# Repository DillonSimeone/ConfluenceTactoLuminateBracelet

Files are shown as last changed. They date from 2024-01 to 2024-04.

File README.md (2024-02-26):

<h1 align="center"><a href="https://bejewelled-kelpie-6a1941.netlify.app/">Gestolumina</a></h1>
<h4 align="center">Gesture Interpreted Light, Sound and Haptics. Towards a Framework for Universal Music Design</h4>

<p align="center">
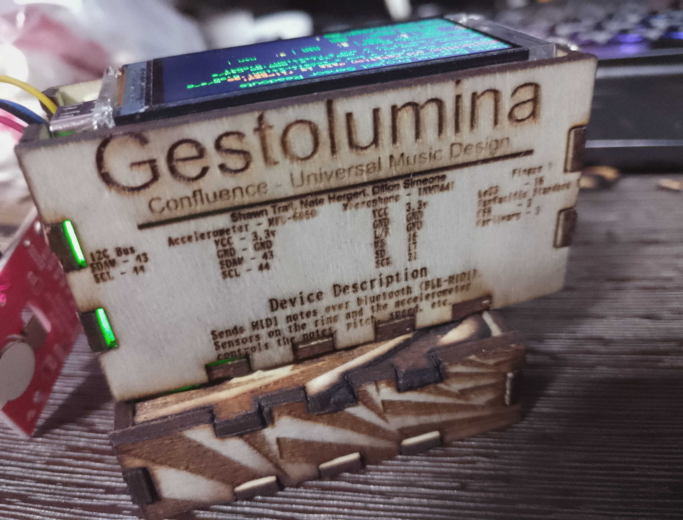
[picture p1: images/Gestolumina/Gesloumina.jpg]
    
</p>
<h1 align="center">Team Members</h1>
<table align="center">
    <thead>
        <th>Shawn Trail, PhD</th>
        <th>Nate Hergert</th>
        <th>Myles De Bastion</th>
    </thead>
    <tbody>
        <tr>   
            <td>CymaSpace</td>
            <td>CymaSpace</td>
            <td>CymaSpace</td>
        </tr>
        <tr>
            <td>www.cymaspace.org</td>
            <td>www.cymaspace.org</td>
            <td>www.cymaspace.org</td>
        </tr>
        <tr>
            <td>Portland, Oregon</td>
            <td>Portland, Oregon</td>
            <td>Portland, Oregon</td>
        </tr>
        <tr>
            <td>shawntrail@gmail.com</td>
            <td>nate@cymaspace.org</td>
            <td>myles@cymaspace.org</td>
        </tr>
    </tbody>
    
</table>
<table align="center">
    <thead>
        <th>Dillon Simeone</th>
        <th>Doga Cavdir, PhD</th>
        <th>Duncan MacConnell, PhD</th>
    </thead>
    <tbody>
    <tr>
        <td>CymaSpace</td>
        <td>Medialogy</td>
        <td>Avid</td>
    </tr>
    <tr>
        <td>www.cymaspace.org</td>
        <td>Aalborg University</td>
        <td><a href="https://www.linkedin.com/in/duncan-macconnell-a4067511a/overlay/contact-info/">linkedIn</a></td>
    </tr>
    <tr>
        <td>Portland, Oregon</td>
        <td>Copnenhagen, Denmark</td>
        <td>Montreal, Quebec, Canada</td>
    </tr>
    <tr>
        <td>dillonsimeone@gmail.com</td>
        <td>Idoga.cadvir@gmail.com</td>
        <td>duncanmacconnell@gmail.com</td>
    </tr>
    </tbody>
</table>

# Intro
<p>
    Two different styles of bracelets are being built as custom musical instruments, one with pixelblaze and another with ESP32. The purpose of those bracelets are to control nearly haptics and LED systems via sensors detecting the wearer's gestures and movements. 
</p>
<h3><a href="https://github.com/DillonSimeone/Gestolumina/tree/main/Arduino%20Code">ESP32 Bracelet (GestoLumina)</a></h3>
<p>A low cost but extremely powerful approach, very beginner-friendly due to being programmed in arduino. Require more elbow grease to get up and running similar to the pixelblaze. However, the bluetooth in nearly all ESP32s makes them very easy to program as bluetooth musical instruments!</p>

<h3><a href="https://github.com/DillonSimeone/Gestolumina/tree/main/Pixelblaze%20Code">Pixelblaze Bracelet</a></h3>
<p>The tool of choice for visualizing sounds with leds. This was the first quick rough prototype, since it was easy to order the sensor extension which comes with all sensors required for the project. Custom firmwork, somewhat accessiable due to its programming language being similar to javascript. No support for TFT displays, arduino libraries, etc. Not as straightfoward to set up as a musical instrument.</p>

# Misc
<h3>Prezi Show</h3>
<p>Confluence built this prezi show for workshops, to quickly give people a crash course into how CymaSpace handles sounds to lights and music theory.</p>
<h3 align="center"><a href="https://prezi.com/view/BKSwKoRpNLLlaCZ8I6HS/">View Prezi</a></h3>

# Videos
<h3>Misc</h3>
<ul>
    <li><a href="https://www.youtube.com/shorts/vZXHRAnROqk">Lasering parts out</a></li>
    <li><a href="https://www.youtube.com/shorts/q6HAHHKfm44">Random reverse engineering for bracelet straps</a></li>
</ul>
<h3>Pixelblaze</h3>
<ul>
    <li><a href="https://www.youtube.com/shorts/bQNIAE6hn9M">Making chassis</a></li>
    <li><a href="https://www.youtube.com/shorts/2__cOaNY4yM">Testing frequency reactive code</a></li>
    <li><a href="https://www.youtube.com/shorts/NpTJMvQrC3I">Testing beats per minute mode</a></li>
</ul>
<h3>GestoLumina</h3>
<ul>
    <li><a href="https://www.youtube.com/watch?v=SJd1xGemtCc">Testing Hallway Monitor</a></li>
    <li><a href="https://www.youtube.com/shorts/A8XjW7fpP0g">Testing ring led reacting to sounds</a></li>
    <li><a href="https://www.youtube.com/shorts/U4VskPwTADo">Testing MPU-6050 1</a></li>
    <li><a href="https://www.youtube.com/shorts/bvzDoGDOsoE ">Testing MPU-6050 2</a></li>
    <li><a href="https://www.youtube.com/shorts/jl-9ZZjW-vE ">Testing MPU-6050 3</a></li>
    <li><a href="https://www.youtube.com/shorts/bEWE7uyCt_Y ">Testing haptics</a></li>
    <li><a href="https://www.youtube.com/shorts/fWRVd8oUweI">Inching toward final form... Too bulky! The pins coming out of the ESP32 board are evil!</a></li>
    <li><a href="https://www.youtube.com/shorts/FxuSiAMirj8"> Second Prototype... It's wearable! The ESP32 is soldered onto a protoboard, and wires to that, which managed to cut down on volume.</li>
</ul>

# Pictures
<h3>Pixelblaze</h3>
<table>
    <tr>
        <td align="center">
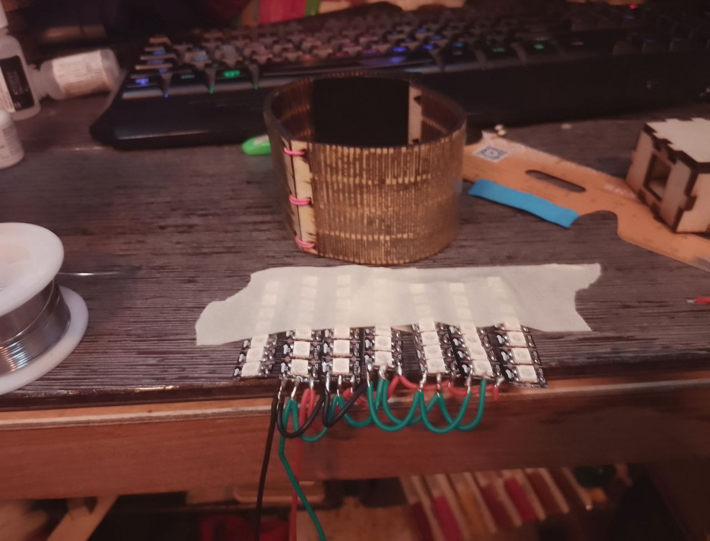
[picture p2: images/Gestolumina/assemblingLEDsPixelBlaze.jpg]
            
        </td>
        <td align="center">
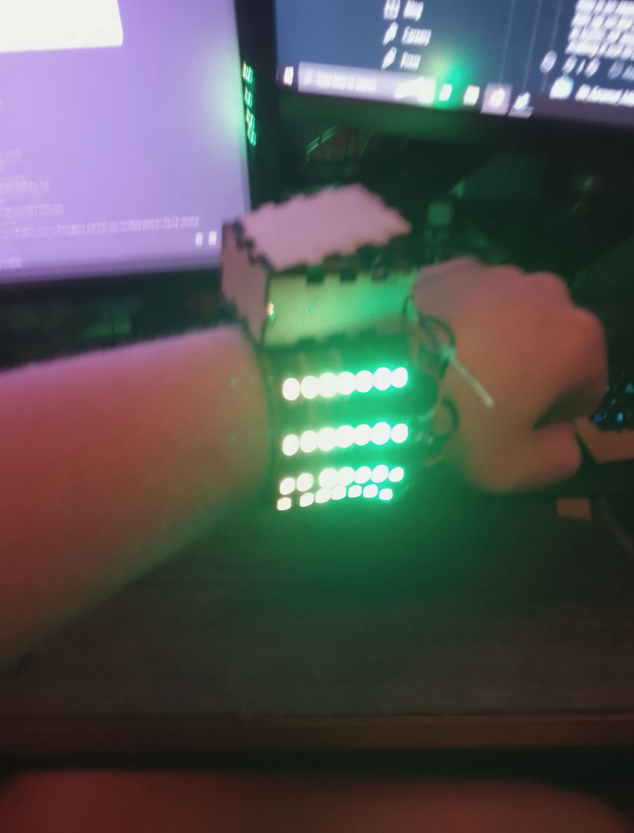
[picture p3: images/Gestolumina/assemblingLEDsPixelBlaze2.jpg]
            
        </td>
        <td align="center">
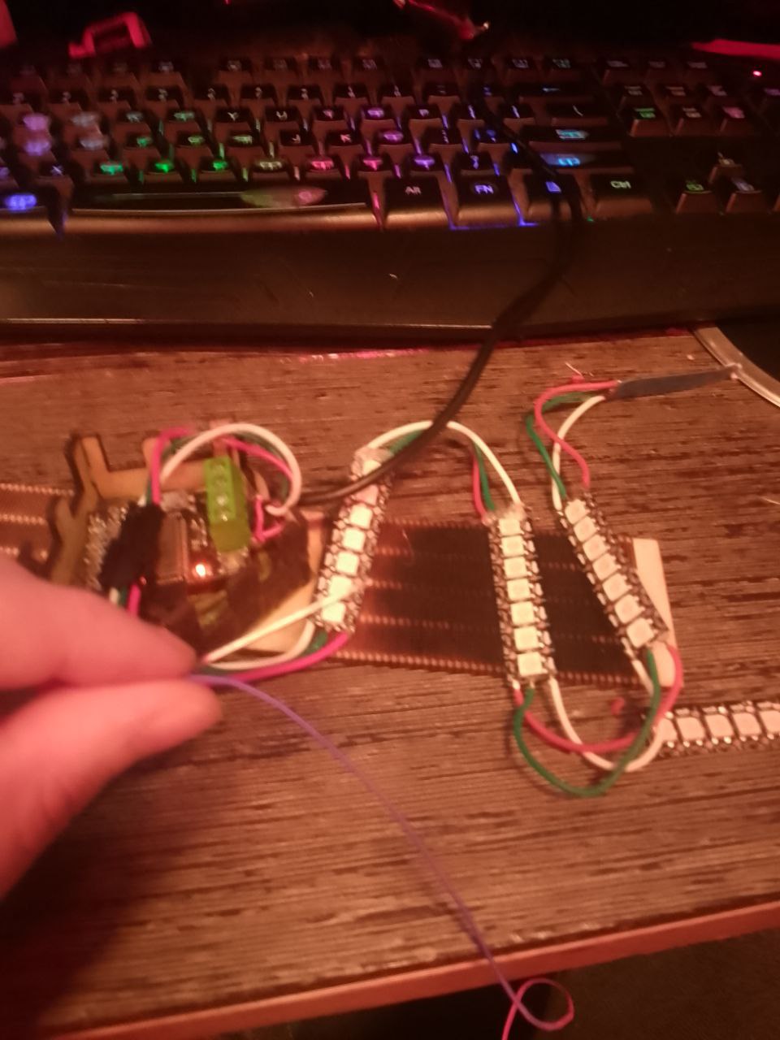
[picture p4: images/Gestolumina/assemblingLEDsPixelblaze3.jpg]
           
        </td>
    </tr>
    <tr>
        <td align="center"> 
            <p>Cutting up and soldering together LED strips so they'll fit on the living hinge bracelet. </p>
        </td>
        <td align="center">
            <p>The pixelblaze bracelet lives!</p>
        </td>
        <td align="center">
            <p>Making a new bracelet and wiring the leds differently. Previously, they was wired in parallel.</p>
        </td>
    </tr>
</table>

<h3>ESP32 (GestoLumina)</h3>
<table>
    <tr>
        <td align="center">
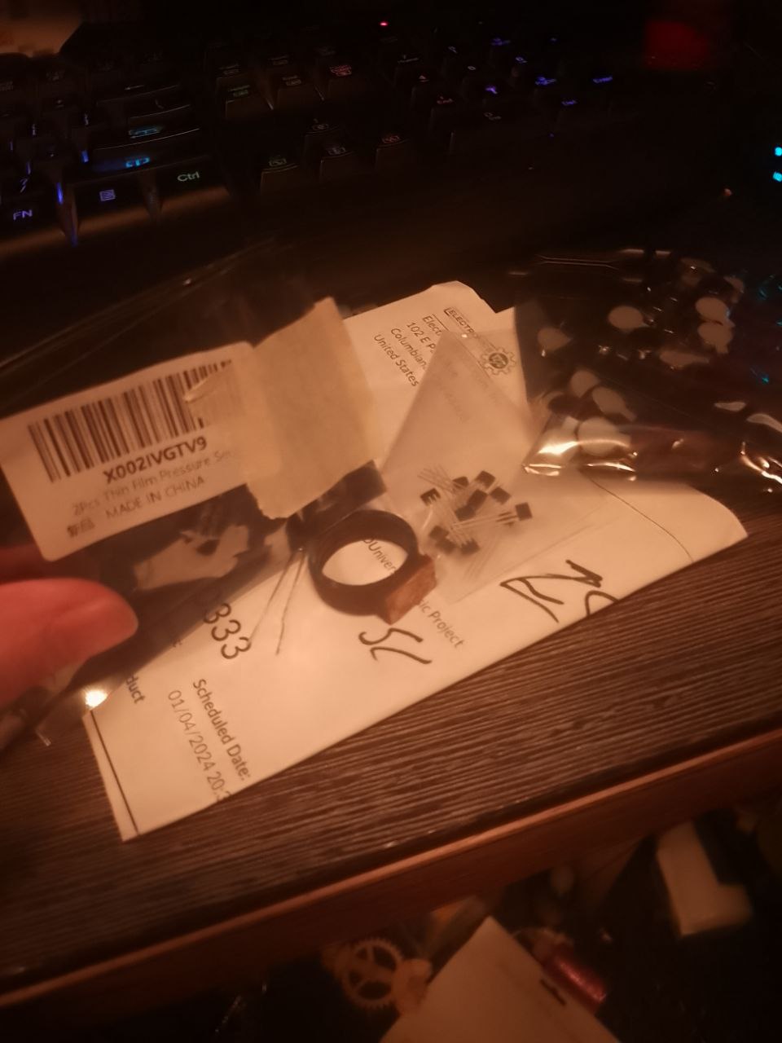
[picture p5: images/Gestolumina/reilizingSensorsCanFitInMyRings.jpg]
            
        </td>
        <td align="center">
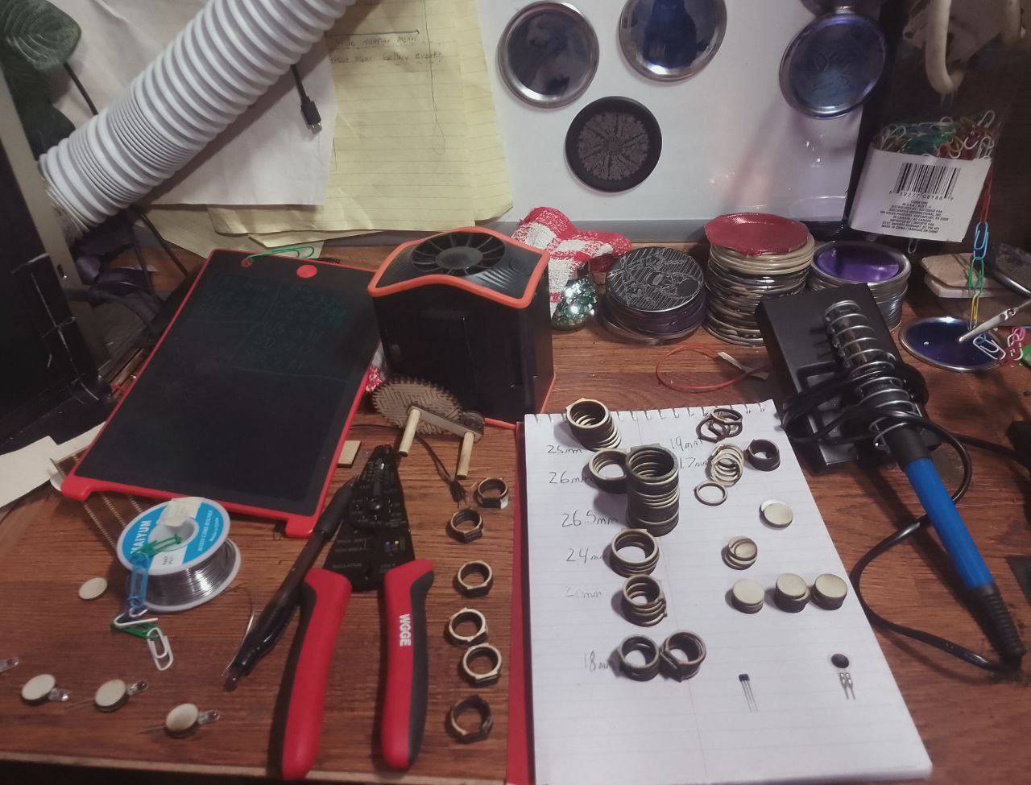
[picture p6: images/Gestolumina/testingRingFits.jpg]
            
        </td>
        <td align="center">
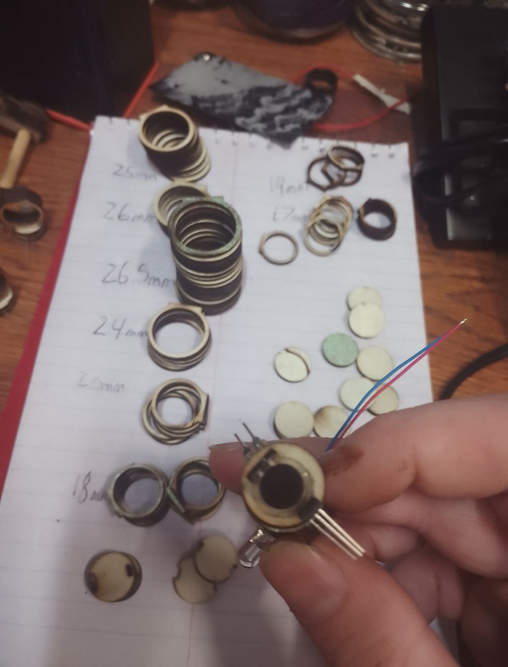
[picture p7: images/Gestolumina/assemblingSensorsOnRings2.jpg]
            
        </td>
    </tr>
    <tr>
        <td align="center">
            <p>The moment when it was realized that most of the sensors would fit neatly into wooden rings made by a laser cutter.</p>
        </td>
        <td align="center">
            <p>Testing which ring size seems to fit on people's fingertips the best. 18mm~ turned out to be the ideal size for those ring designs.</p>
        </td>
        <td align="center">
            <p>Assembling sensors on the rings, it went by pretty nicely.</p>
        </td>
    </tr>
    <tr>
        <td align="center">
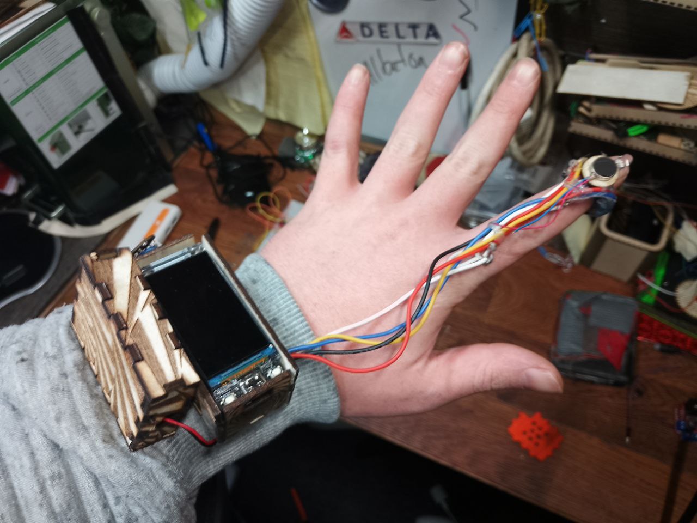
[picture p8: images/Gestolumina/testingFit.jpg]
            
        </td>
        <td align="center">
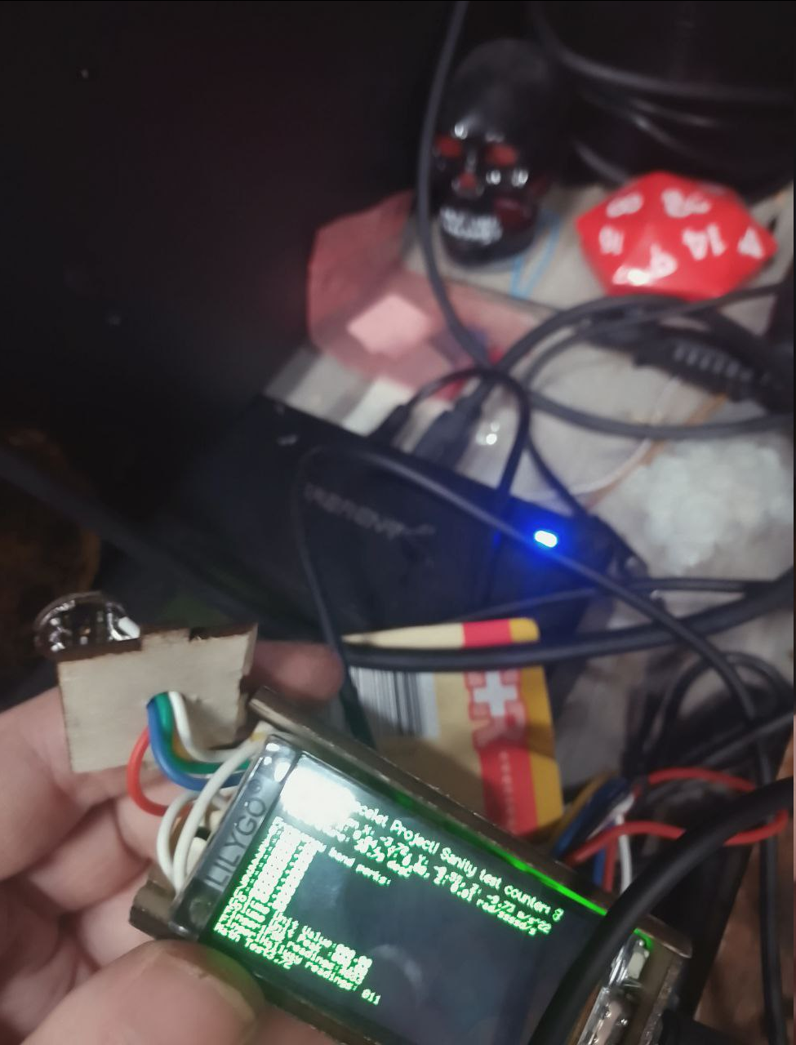
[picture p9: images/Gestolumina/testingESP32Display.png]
            
        </td>
        <td align="center">
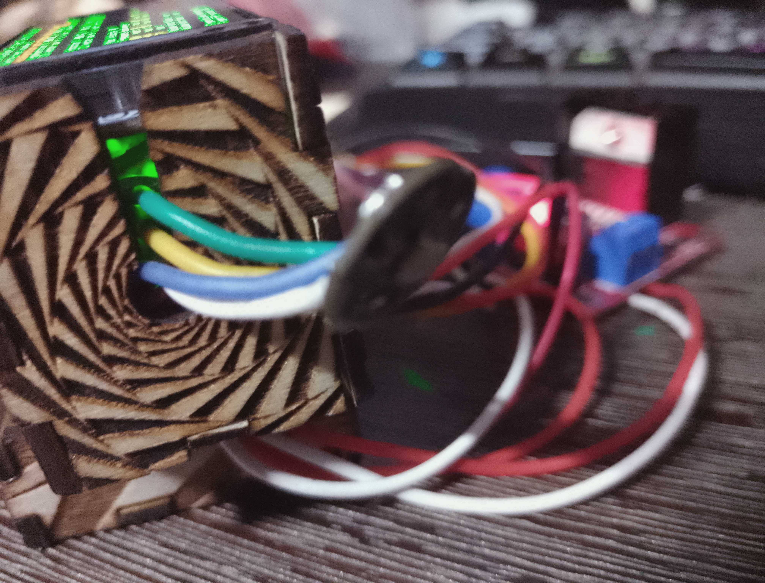
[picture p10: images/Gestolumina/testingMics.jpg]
            
        </td>
    </tr>
    <tr>
        <td align="center">
            <p>It fits!</p>
        </td>
        <td align="center"> 
            <p>Displaying all sensor readouts on the screen for easier development and troubleshooting.</p>
        </td>
        <td align="center"> 
            We was careful to laser the box in a way where sensors and the like can be added or removed without desoldering wires, breaking the box, etc.
        </td>
    </tr>
    <tr>
        <td align="center">
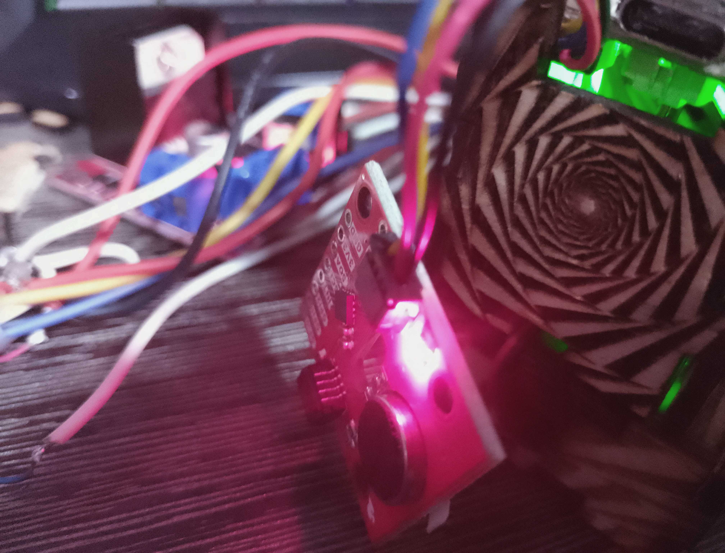
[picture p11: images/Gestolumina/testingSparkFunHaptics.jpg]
            
        </td>
        <td align="center">
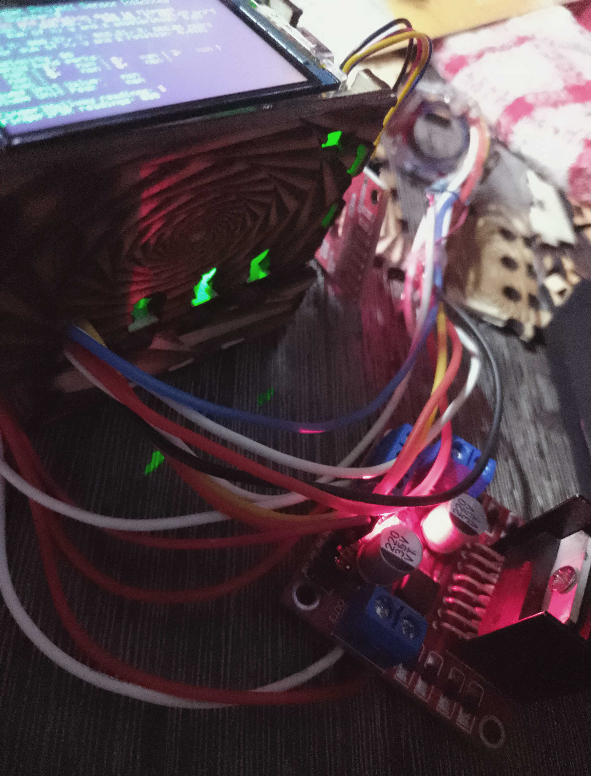
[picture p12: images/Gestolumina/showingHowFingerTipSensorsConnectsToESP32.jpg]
            
        </td>
        <td align="center">
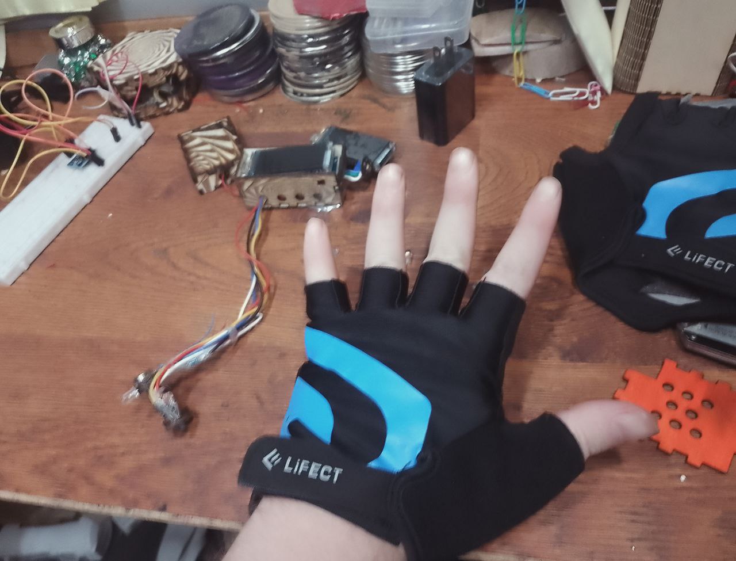
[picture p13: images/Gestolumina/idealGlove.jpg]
            
        </td>
    </tr>
    <tr>
        <td align="center">
            <p>Testing the sparkfun haptic driver, it turned out to be really weak. Barely noticeable at max power. That's 3v haptics for you!</p>
        </td>
        <td align="center">
            <p>Added a L298N H-bridge to control the haptics with, much better!</p>
        </td>
        <td align="center">
            <p>This half glove is what the entire system will be sewn to eventually!</p>
        </td>
    </tr>
    <tr>
        <td align="center">
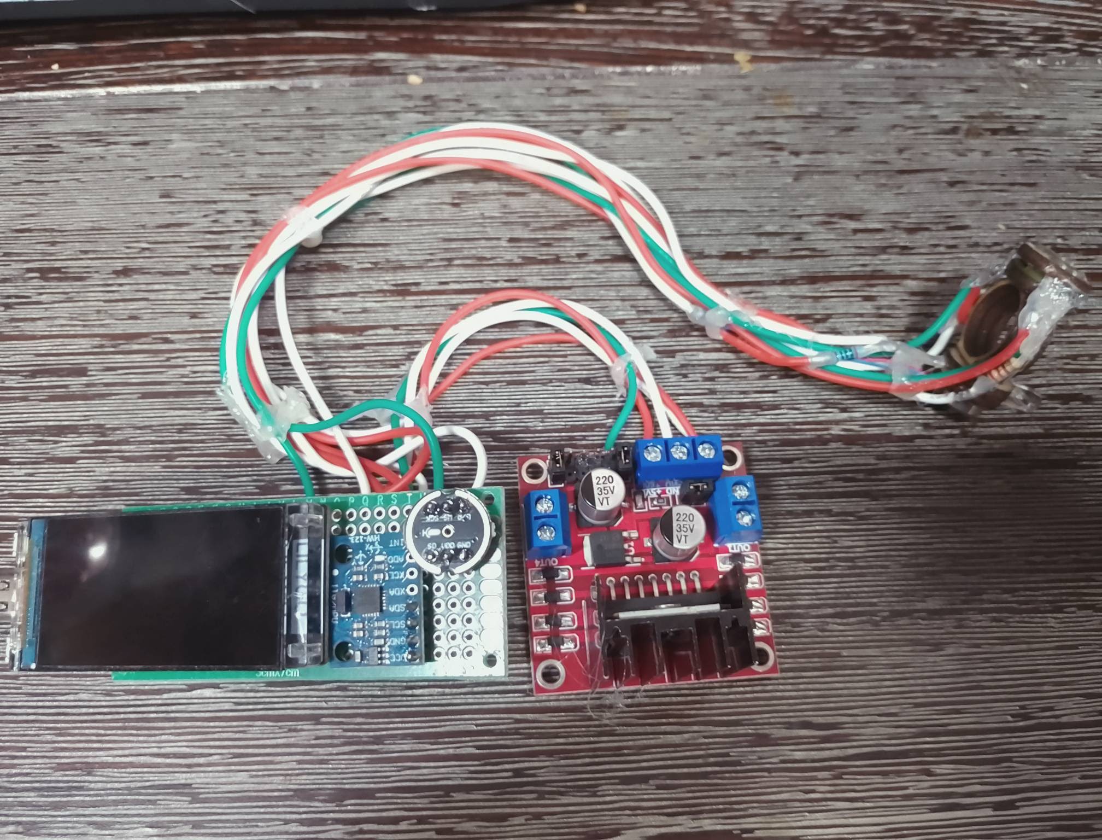
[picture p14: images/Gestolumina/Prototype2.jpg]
            
        </td>
        <td align="center">
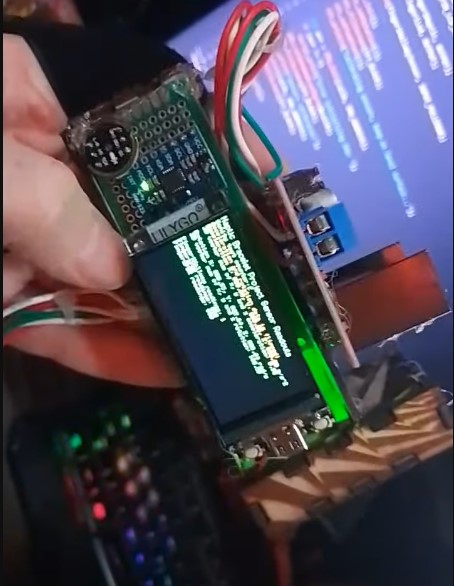
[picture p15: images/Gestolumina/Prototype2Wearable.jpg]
            
        </td>
        <td align="center">
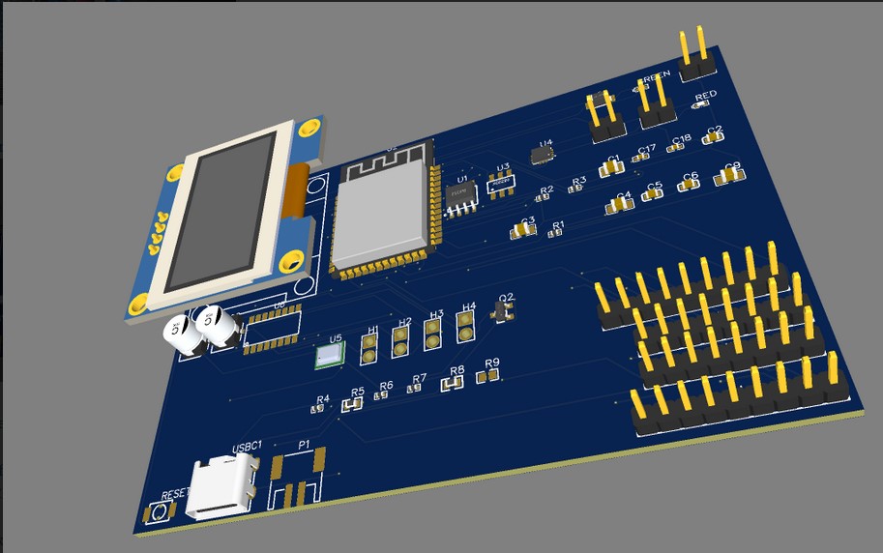
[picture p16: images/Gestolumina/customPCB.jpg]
            
        </td>
    </tr>
    <tr>
        <td align="center">
            <p>Protoboard used! Much better. It was at this point where the team realized that a custom PCB would be much better.</p>
        </td>
        <td align="center">
            <p>After some hot glue and stuff was added... Bam bam, it's wearable now! And can send midi notes with gestures!</p>
        </td>
        <td align="center">
            <p>Designing the custom PCB for the first time... This is just the beginning! A lot of things to study, textbooks to read and videos to watch.</p>
        </td>
    </tr>
</table>

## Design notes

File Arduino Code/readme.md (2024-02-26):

<h3><a href="https://github.com/DillonSimeone/Gestolumina/tree/main/Arduino%20Code/FrequencyReactiveTacile">FrequencyReactiveTacile</a></h3>
 
<p>The first GeLu Prototype. Only one finger input, and one IMU.</p>

<h3><a href="https://github.com/DillonSimeone/Gestolumina/tree/main/Arduino%20Code/FrequencyReactiveTacile2">FrequencyReactiveTacile2</a></h3>
 
<p>The second GeLu Prototype. Two finger inputs, and one IMU.</p>

<h3>audioSanityTest</h3>
<p>Uses the same i2s pins as the above script... And it works!</p>

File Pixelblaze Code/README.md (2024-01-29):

# Intro
<h3>Pixelblaze</h3>
<p>An awesome led controller ESP32 commonly used by burning man partygoers, due to its live coding ability and how easy it is to connect it to nearly any LED lightings along with analog input/outputs.</p>
<h4 align="center"><a href="https://electromage.com/pixelblaze">Pixelblaze Website</a></h4>

<p>
  Gestolumina's first prototype used a pixelblaze V3 along with a <a href="https://electromage.com/docs/sensor-expansion-board">sensor extension</a>, making it very easy to get up and running right away. Barely any soldering needed, slap the hat on and you're ready to get to casting led magic!
</p>

<p>
  One thing that was made really easy with this system was beats detection. An audio engineer, Jeff Vyduna, was able to come up with a script that detects beats per minutes by looking for drops and rises across certain frequencies within a certain time frame. It works really well! We was able to extract his beats detection algorithm and modifiy it into a beats per minute detector pretty easily, making it possible to modify current animations based on the current beats per minute. 
</p>

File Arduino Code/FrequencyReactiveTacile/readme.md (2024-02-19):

# Device Description
This sends out midi notes via bluetooth (BLE-MIDI). The sensors on the ring and MPU-6050 affects what notes are sent, velocity, etc.

# Libraries
<h4>MPU sensor data + calibration</h4>
<blockquote>
	https://github.com/LiquidCGS/FastIMU
	<p>Made it really easy to just plug those MPU sensors in and be done with it!</p>
</blockquote>

<h4>Audio processing</h4>
<blockquote>
	https://github.com/sheaivey/ESP32-AudioInI2S
	<p>Does magic on the audio to get frequency data, volume level, etc.</p>
</blockquote>

<h4>Arduino BLE-MIDI</h4>
<blockquote>
	https://github.com/lathoub/Arduino-BLE-MIDI 
	<p>Bluetooth to MIDI</p>
</blockquote>

<h4>Sparkfun Haptic Driver</h4>
<blockquote>
	https://github.com/sparkfun/SparkFun_Qwiic_Haptic_Driver_DA7280_Arduino_Library
	<p>Haptics</p>
</blockquote>

# Hardwares
<div>
	<h4>Mircocontroller</h4>
	<blockquote>
		<a href="https://www.amazon.com/LILYGO-T-Display-S3-ESP32-S3-Development-Soldered/dp/B0BF542H39/">LilyGo T-Display-S3</a>
		<p>Tiny, bluetooth, wifi, battery charge controller, LCD display and pins. What more can a guy ask for?</p>
	</blockquote>
	
</div>

<div>
	<h4>Battery</h4>
	<blockquote>
		<a href="https://www.amazon.com/MakerFocus-Rechargable-Protection-Insulated-Development/dp/B08T6QS58J/?th=1">3.7V Lithium Rechargeable Battery</a>
		<p>Cheap batteries.</p>
	</blockquote>
	
</div>

<div>
	<h4>Haptics</h4>
	<blockquote>
		<a href="https://www.amazon.com/SparkFun-Qwiic-Haptic-Driver-Built/dp/B096YHK485">SparkFun Haptic Driver</a>
		<b> NOT IN USE, TOO WEAK TO NOTICE</b>
		<p>Sparkfun marketed those as accurate audio to haptic hardwares... They did not mention that they're so weak that it takes effort to notice them.</p>
		<a href="https://www.amazon.com/SparkFun-development-soldering-Breadboardable-Chain-able/dp/B07RB2LRH5">Cable hook up kit</a>
		<b> NOT IN USE, NO OTHER I2C QWICC SENSORS IN USE. </b>
		<p>Ordered specifically for the Sparkfun Haptics, just to see how those cables are like.</p>
		<a href="https://www.amazon.com/dp/B0C5JCF5RS">L298N</a>
		<p>Good old time-tested H-bridges. They just work, and will happily melt your haptics if you run way too much power through them. They're awesome... The best!</p>
		<a href="https://www.amazon.com/tatoko-Vibration-Button-Type-Vibrating-Appliances/dp/B07Q1ZV4MJ/">Mini Vibration Motors </a>
		<p>Those actually works with a range of 3v to 5v without much issues. Nice and cheap.</p>
	</blockquote>
	
</div>

<div>
	<h4>Microphones</h4>
	<blockquote>
		<a href="https://www.amazon.com/dp/B092HWW4RS">INMP441</a>
		<p>Time-tested microphones, countless people have used those with great success.</p>
	</blockquote>
</div>

<div>
	<h4>Hallway Sensors</h4>
	<blockquote>
		<a href="https://www.amazon.com/SparkFun-Hall-Effect-Sensor-AH1815-Non-Latching/dp/B07DM7WBCG">AH1815</a>
		<p>Time-tested hallway sensors. There's many uses for them.</p>
	</blockquote>
</div>

<div>
	<h4>Film Pressure Sensor</h4>
	<blockquote>
		<a href="https://www.amazon.com/dp/B07T1CHY58">DF9-16 High Precise Force Sensitive Resistor</a>
		<p>Tiny and cheap, they work for fingertips.</p>
	</blockquote>
	
</div>

<div>
	<h4></h4>

</div>

# Midi notes programmed
	Channel 1:
		Accelerometer - Sends Midi Note 53 when moved quickly enough in any directions, velocity affected by top speed.
	Channel 2:
		Index finger - Sends Midi Note 43, velocity affected by how hard the FSR is pressed.

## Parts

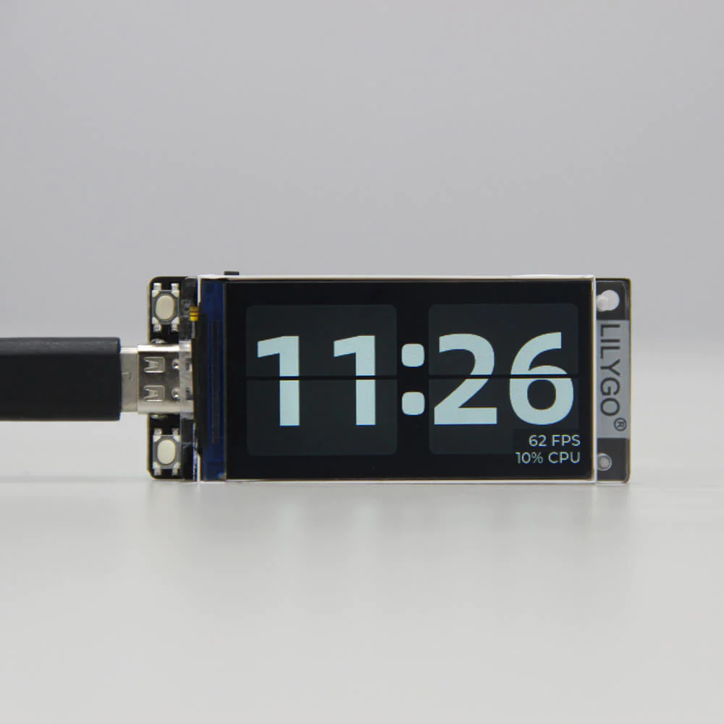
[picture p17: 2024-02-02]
images/parts/Lilygo-T-display_11.webp

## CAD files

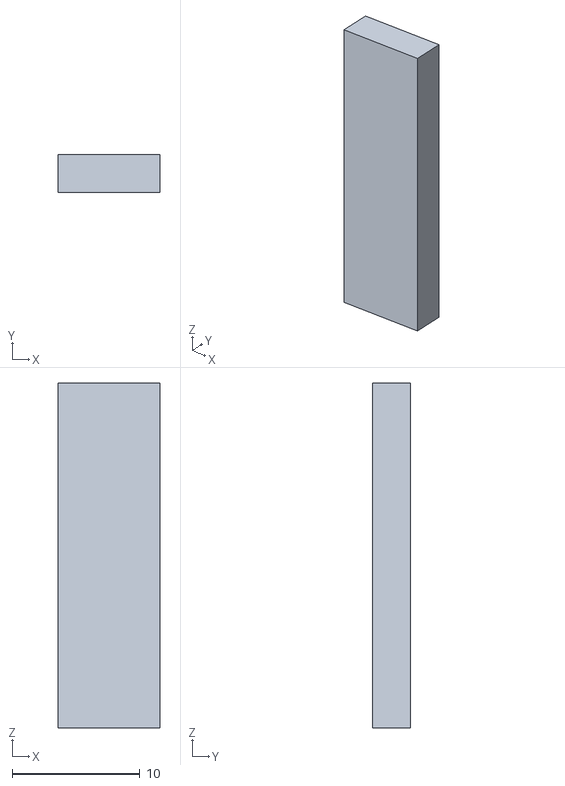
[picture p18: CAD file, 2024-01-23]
3D models/MagnetHolderShort.stl
8.00 x 3.00 x 27.0

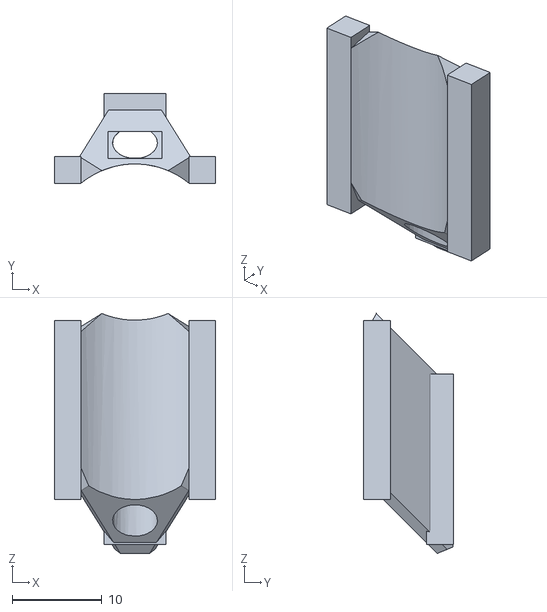
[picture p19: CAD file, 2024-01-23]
3D models/HallwaySensorHolder.stl
18.0 x 10.0 x 26.8

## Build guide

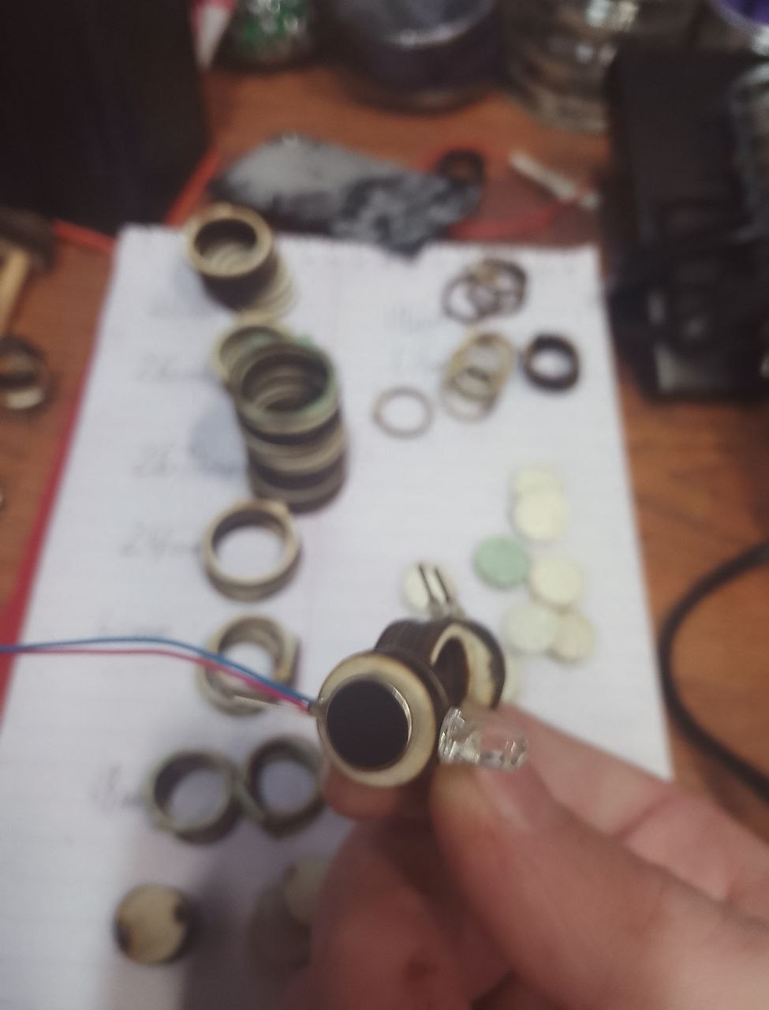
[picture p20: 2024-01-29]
images/Gestolumina/assemblingSensorsOnRings3.jpg

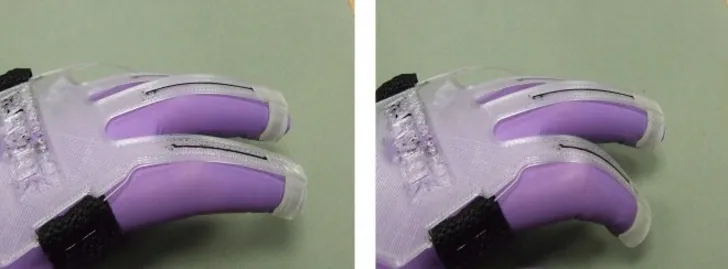
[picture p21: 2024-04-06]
images/datagloves/3DMotionSensingGlovePrinted.webp

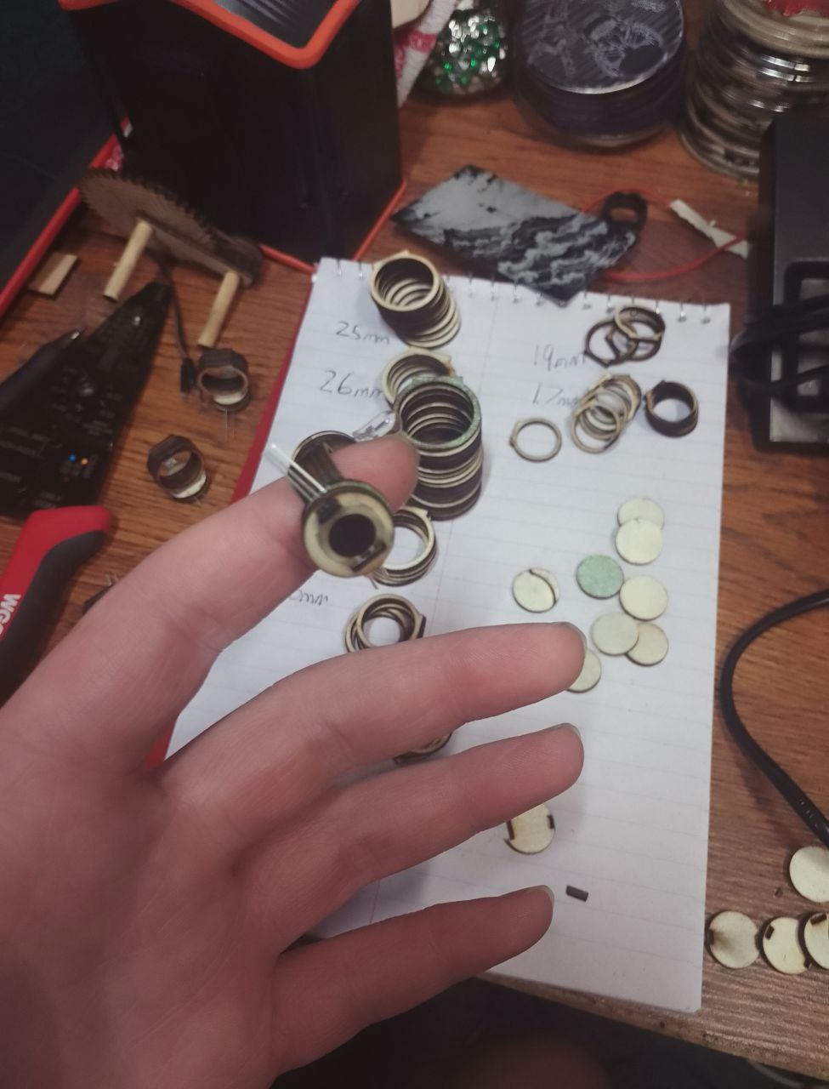
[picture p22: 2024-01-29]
images/Gestolumina/assemblingSensorsOnRings.jpg

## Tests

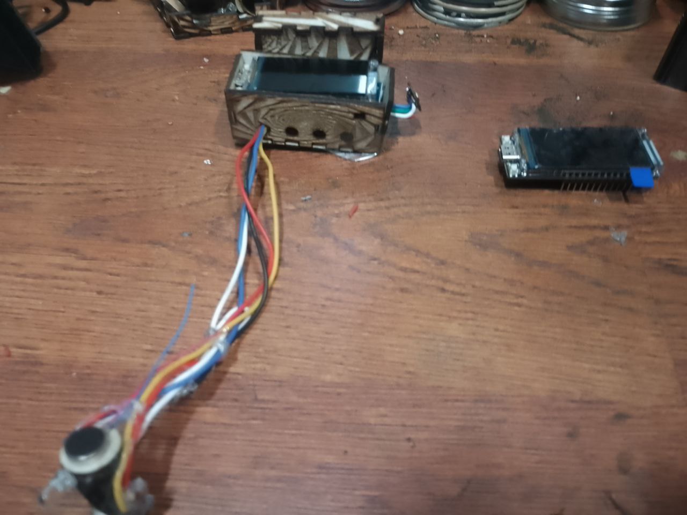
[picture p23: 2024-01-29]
images/Gestolumina/testingBoxFit.jpg

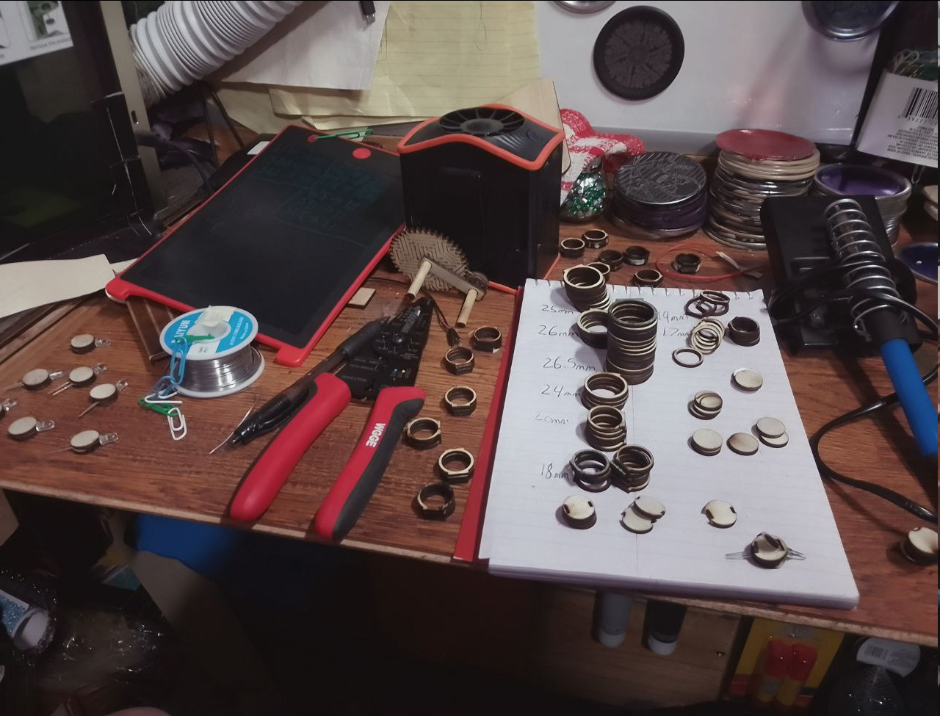
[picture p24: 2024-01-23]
images/Gestolumina/ringsTesting.png

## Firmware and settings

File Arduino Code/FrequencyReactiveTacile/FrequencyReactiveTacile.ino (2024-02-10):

/*
Last modified on: 1/23/2024

Confluence - Universial Music Design
  Gestolumina Prototype 1

Sends MIDI notes over bluetooth (BLE-MIDI). Sensors on the ring and the accelermeter controls the notes, pitch, speed, etc.

Programmer: Dillon Simeone
*/

#include "pin_config.h"
#include <Wire.h> //pin 43: SDA pin 44: SCL. Is the default pins of LilyGo. 

//Screen
#include <SPI.h>
#include <TFT_eSPI.h> // Graphics and font library for ST7735 driver chip
TFT_eSPI tft = TFT_eSPI();  // Invoke library, pins defined in User_Setup.h


//Bluetooth
#include <BLEMIDI_Transport.h>
#include <hardware/BLEMIDI_ESP32.h>
BLEMIDI_CREATE_INSTANCE("Gestolumina Prototype 1", MIDI)

//ET's index finger
#define finger1Led 16
#define finger1FSR 2
#define finger1HallwaySensor 3 //It's kinda of tricky to trigger those hallway sensors. They require magnets touching them precisely right or they won't trigger. Maybe stronger magnets are required?
int finger1HallwaySensorState;
int finger1HallwaySensorPreviousState = LOW;
unsigned long finger1HallwaySensorlastDebounceTime = 0;
unsigned long debounceDelay = 50;

//Mic pins NOT WORKING
#include <AudioInI2S.h>
#include <AudioAnalysis.h>
#define BCK_PIN 21
#define WS_PIN 18
#define DATA_PIN 17 
AudioInI2S mic(BCK_PIN, WS_PIN, DATA_PIN); // defaults to RIGHT channel.
#define SAMPLE_SIZE 1024 // Buffer size of read samples
#define SAMPLE_RATE 44100 // Audio Sample Rate
int32_t samples[SAMPLE_SIZE]; // I2S sample data is stored here
#define BAND_SIZE 8 // powers of 2 up to 64, defaults to 8
AudioAnalysis audioInfo;


//MPU6050 sensor
#define IMU_ADDRESS 0x68    //Change to the address of the IMU
#include "I2Cdev.h"
#include "FastIMU.h" //Pretty fire library that made a lot of the set-up painless with the MPU.
MPU6050 IMU;
calData calib = { 0 };  //Calibration data
AccelData accelData;    //Sensor data
GyroData gyroData;

//SparkFun Qwiic Haptic Driver DA7280 Dillon's comment: This is WEAK as heck. I barely can notice it running even on max settings. Lame.
#include "Haptic_Driver.h"
Haptic_Driver hapDrive;
#define l298nMotor1 1

int counter = 0;

//Turns out when batteries are plugged into the LilyGo's battery charger port, the screen goes blank. Below is the fix.
#define PIN_POWER_ON 15 // LCD and battery Power Enable
#define PIN_LCD_BL 38 // BackLight enable pin (see Dimming.txt)

void setup() {
  Wire.begin(43, 44);  //SDA, SCL
  
   mic.begin(SAMPLE_SIZE, SAMPLE_RATE); // Starts the I2S DMA port.
  // audio analysis setup
  audioInfo.setNoiseFloor(10);       // sets the noise floor
  audioInfo.normalize(true, 0, 255); // normalize all values to range provided.
  // audioInfo.autoLevel(AudioAnalysis::ACCELERATE_FALLOFF, 1); // uncomment this line to set auto level falloff rate
  audioInfo.bandPeakFalloff(AudioAnalysis::EXPONENTIAL_FALLOFF, 0.05); // set the band peak fall off rate
  audioInfo.vuPeakFalloff(AudioAnalysis::EXPONENTIAL_FALLOFF, 0.05);    // set the volume unit peak fall off rate

  //Battery screen fix continued. 
  pinMode(PIN_POWER_ON, OUTPUT); //triggers the LCD backlight
  pinMode(PIN_LCD_BL, OUTPUT); // BackLight enable pin

  digitalWrite(PIN_POWER_ON, HIGH);
  digitalWrite(PIN_LCD_BL, HIGH);

  if( !hapDrive.begin())
    Serial.println("Could not communicate with Haptic Driver.");
  else
    Serial.println("Qwiic Haptic Driver DA7280 found!");

  if( !hapDrive.defaultMotor() ) 
    Serial.println("Could not set default settings.");
  hapDrive.enableFreqTrack(false);
  hapDrive.setOperationMode(DRO_MODE);

  pinMode(l298nMotor1, OUTPUT);

  pinMode(finger1Led, OUTPUT);
  pinMode(finger1HallwaySensor, INPUT_PULLDOWN);

  tft.init();
  tft.setRotation(1);
  tft.fillScreen(TFT_BLACK);
  tft.setTextFont(2);
  tft.println("Calibrating sensors, keep on level surface...");

  int err = IMU.init(calib, IMU_ADDRESS);
  if (err != 0) 
    Serial.print("Error initializing IMU: "); 
  IMU.calibrateAccelGyro(&calib);
  tft.fillScreen(TFT_BLACK);
  tft.print("Sensors calibrated!");
  IMU.init(calib, IMU_ADDRESS);
  tft.fillScreen(TFT_BLACK);

 

  MIDI.begin();
}

void mpu6050Colors(float data){
  if(data > 0.5)
    tft.setTextColor(TFT_YELLOW, TFT_BLACK);
  if(data > 1)
    tft.setTextColor(TFT_PURPLE, TFT_BLACK);
  if(data > 1.5)
    tft.setTextColor(TFT_ORANGE, TFT_BLACK);
  if(data > 2)
    tft.setTextColor(TFT_RED, TFT_BLACK);
  tft.printf("%06.2f",abs(data));
  tft.setTextColor(TFT_GREEN, TFT_BLACK);
}

void loop() {
  IMU.update();
  IMU.getAccel(&accelData);
  IMU.getGyro(&gyroData);

  //debounce magic for hallway sensor
  int finger1HallwaySensorReading = digitalRead(finger1HallwaySensor);

  if(finger1HallwaySensorReading != finger1HallwaySensorPreviousState)
    finger1HallwaySensorlastDebounceTime = millis();
  
  if((millis() - finger1HallwaySensorlastDebounceTime) > debounceDelay)
    if(finger1HallwaySensorReading != finger1HallwaySensorState)
      finger1HallwaySensorState = finger1HallwaySensorReading;

  finger1HallwaySensorPreviousState = finger1HallwaySensorReading;

  /* Get new sensor events with the readings */
  mic.read(samples); // Stores the current I2S port buffer into samples.
  audioInfo.computeFFT(samples, SAMPLE_SIZE, SAMPLE_RATE);
  audioInfo.computeFrequencies(BAND_SIZE);
  float *bands = audioInfo.getBands();
  float *peaks = audioInfo.getPeaks();
  float vuMeter = audioInfo.getVolumeUnit();
  float vuMeterPeak = audioInfo.getVolumeUnitPeak();

  //Setting up screen for magic
  tft.setTextColor(TFT_GREEN, TFT_BLACK);
  tft.setCursor(0,0,2);
  tft.println("Haptic Bracelet Project Sensor Readouts");
  tft.setTextFont(1);
  tft.print("Sanity test counter:");
  tft.println(counter);
  counter++;
  if(counter > 9)
    counter = 0;
  
  tft.setTextColor(TFT_ORANGE, TFT_BLACK);
  tft.println("Acceleration and rotation data is flipped!");
  tft.setTextColor(TFT_GREEN, TFT_BLACK);
  tft.print("Acceleration X: "); //Oddly, it seems that acceleration on this mystery MPU is actually the rotation?
  mpu6050Colors(accelData.accelX);

  tft.print(", Y: ");
  mpu6050Colors(accelData.accelY);

  tft.print(", Z: ");
  mpu6050Colors(accelData.accelZ + 1);
  tft.println(" m/s^2");
  tft.print("3D vector sum of x, y and z acceleration: ");
  double totalAcceleration = sqrt(
    accelData.accelX * accelData.accelX +
    accelData.accelY * accelData.accelY +
    accelData.accelZ * accelData.accelZ);
  tft.println(totalAcceleration);
  tft.println("");

  tft.print("Rotation X: ");
  mpu6050Colors(gyroData.gyroX);
  tft.print(", Y: ");
  mpu6050Colors(gyroData.gyroY);
  tft.print(", Z: ");
  mpu6050Colors(gyroData.gyroZ);
  tft.println(" rad/s");
  tft.print("3D vector sum of x, y and z rotation: ");
  double totalAcceleration2 = sqrt(
    gyroData.gyroX * gyroData.gyroX +
    gyroData.gyroY * gyroData.gyroY +
    gyroData.gyroZ * gyroData.gyroZ);
  tft.println(totalAcceleration2);
  //Midi velocrity
  tft.println("");

  int midiVelocity = map(totalAcceleration2, 0, 500, 0, 127);
  tft.print("Midi Velocity: ");
  tft.println(midiVelocity);
  tft.println("");

  /*
  tft.print("Temperature: ");
  tft.print(IMU.getTemp());
  tft.println(" degC");
  */ 

  tft.println("Frequency band perks: ");

  for (int i = 0; i < BAND_SIZE; i++){
    tft.setTextColor(TFT_YELLOW, TFT_BLACK);
    tft.printf("%d:", i);
    tft.setTextColor(TFT_GREEN, TFT_BLACK);
    tft.printf("%06.2f | ", peaks[i]);
    if(i%3 == 0 && i > 0) // Is an even loop and not zero
      tft.println(""); // Line break.
    if(peaks[1] > 50)
      digitalWrite(finger1Led, HIGH);
    else
      digitalWrite(finger1Led, LOW);
  }
  tft.println("");

 

  // also send the vu meter data
  tft.printf("Volume Unit Value:%06.2f\nVolume Unit Peak :%06.2f\n", vuMeter, vuMeterPeak);
  tft.println("");

  tft.print("Finger1Hallway readings: ");
  if(finger1HallwaySensorReading != 0)
    tft.setTextColor(TFT_YELLOW, TFT_BLACK); //I should turn this into a function... Hmm. Accepts string, colors, colors. Switch to color 1 for output, then go back to color 2. 
  tft.println(finger1HallwaySensorReading);
  tft.setTextColor(TFT_GREEN,TFT_BLACK);
  

  tft.print("Finger1FSR readings: ");
  double finger1FSRReading = analogRead(finger1FSR);

  if(finger1FSRReading < 25){
    tft.setTextColor(TFT_GREEN,TFT_BLACK);
    hapDrive.setVibrate(0);
    digitalWrite(l298nMotor1, LOW);
    MIDI.sendNoteOn(60, midiVelocity, 1); //Note, speed, channel
  }
  if(finger1FSRReading > 50){
    hapDrive.setVibrate(127); //So weak... I barely can feel the vibrations. This is the max settings.
    digitalWrite(l298nMotor1, HIGH);
    tft.setTextColor(TFT_YELLOW, TFT_BLACK);
    MIDI.sendNoteOn(61, midiVelocity, 1); 
  }
  if(finger1FSRReading > 75){
    tft.setTextColor(TFT_RED, TFT_BLACK);
    MIDI.sendNoteOn(62, midiVelocity, 1);
  }
  if(finger1FSRReading > 100){
    tft.setTextColor(TFT_PURPLE, TFT_BLACK);
    MIDI.sendNoteOn(63, midiVelocity, 1); 
  }  

  tft.printf("%03d", (int)finger1FSRReading);
  tft.setTextColor(TFT_GREEN, TFT_BLACK);

  MIDI.sendNoteOn(midiVelocity, map(finger1FSRReading, 0, 200, 0, 127), 2); // 200 seems to be the hardest I can press it without the sensor going wonky.
  MIDI.sendNoteOn(midiVelocity, map(vuMeterPeak, 0, 100, 0, 127), 3); //The mic broke before this was coded in, so I'm just recalling numbers from memory. I think the meterPeak ranged from 0 to 100, from testing via shouting at the mic.
  MIDI.sendNoteOn(map(vuMeterPeak, 0, 100, 0, 127), midiVelocity, 4);

  delay(50); //No special reasons for choosing 50ms. It just works. Going faster seems to work fine. I've heard that you need to have at least 2ms delay or you'll get the same readings from the MPU-6050 sensor.
}

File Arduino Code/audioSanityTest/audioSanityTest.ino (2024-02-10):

/*
  ESP32 I2S Microphone Sample
  esp32-i2s-mic-sample.ino
  Sample sound from I2S microphone, display on Serial Plotter
  Requires INMP441 I2S microphone

  DroneBot Workshop 2022
  https://dronebotworkshop.com
*/


#include "pin_config.h"
#include <Wire.h> //pin 43: SDA pin 44: SCL. Is the default pins of LilyGo. 

// Include I2S driver
#include <driver/i2s.h>

//Screen
#include <SPI.h>
#include <TFT_eSPI.h> // Graphics and font library for ST7735 driver chip
TFT_eSPI tft = TFT_eSPI();  // Invoke library, pins defined in User_Setup.h

// Connections to INMP441 I2S microphone //WORKING!
#define I2S_WS 18
#define I2S_SD 17
#define I2S_SCK 21

// Use I2S Processor 0
#define I2S_PORT I2S_NUM_0

// Define input buffer length
#define bufferLen 64
int16_t sBuffer[bufferLen];

void i2s_install() {
  // Set up I2S Processor configuration
  const i2s_config_t i2s_config = {
    .mode = i2s_mode_t(I2S_MODE_MASTER | I2S_MODE_RX),
    .sample_rate = 44100,
    .bits_per_sample = i2s_bits_per_sample_t(16),
    .channel_format = I2S_CHANNEL_FMT_ONLY_LEFT,
    .communication_format = i2s_comm_format_t(I2S_COMM_FORMAT_STAND_I2S),
    .intr_alloc_flags = 0,
    .dma_buf_count = 8,
    .dma_buf_len = bufferLen,
    .use_apll = false
  };

  i2s_driver_install(I2S_PORT, &i2s_config, 0, NULL);
}

void i2s_setpin() {
  // Set I2S pin configuration
  const i2s_pin_config_t pin_config = {
    .bck_io_num = I2S_SCK,
    .ws_io_num = I2S_WS,
    .data_out_num = -1,
    .data_in_num = I2S_SD
  };

  i2s_set_pin(I2S_PORT, &pin_config);
}

void setup() {

  // Set up Serial Monitor
  Serial.begin(115200);
  Serial.println(" ");

  // Set up I2S
  i2s_install();
  i2s_setpin();
  i2s_start(I2S_PORT);

  tft.init();
  tft.setRotation(1);
  tft.fillScreen(TFT_BLACK);



}

void loop() {

  // False print statements to "lock range" on serial plotter display
  // Change rangelimit value to adjust "sensitivity"
  int rangelimit = 3000;
  Serial.print(rangelimit * -1);
  Serial.print(" ");
  Serial.print(rangelimit);
  Serial.print(" ");

  // Get I2S data and place in data buffer
  size_t bytesIn = 0;
  esp_err_t result = i2s_read(I2S_PORT, &sBuffer, bufferLen, &bytesIn, portMAX_DELAY);

  if (result == ESP_OK)
  {
    // Read I2S data buffer
    int16_t samples_read = bytesIn / 8;
    if (samples_read > 0) {
      float mean = 0;
      for (int16_t i = 0; i < samples_read; ++i) {
        mean += (sBuffer[i]);
      }

      // Average the data reading
      mean /= samples_read;

      // Print to serial plotter
      Serial.println(mean);
      tft.fillScreen(TFT_BLACK);
      tft.setTextColor(TFT_GREEN, TFT_BLACK);
      tft.setCursor(0,0,2);
      tft.print(mean);
    }
  }
  delay(20);
}

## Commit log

2024-01-03 Add Laser cutting files
2024-01-23 Laser cut files and current Gestolumina code added.
    Big push! Will this be a powerful enough spark to kick off the entire project?
    [HallwaySensorHolder.stl, MagnetHolderShort.stl]
2024-02-08 News on current happenings!
2024-02-10 Progression on solving the mystery behind the i2s mics not working
    [FrequencyReactiveTacile.ino, audioSanityTest.ino]
2024-02-17 Prototype 2 code improved
    No audio support for now, but audio works and bluetooth is very nice.
2024-03-01 Part 2 of audio reactive update in process
    Some code clean up,.
    Sadly, there's no easy way around the anti-autoplay rules, so the user must interact with the site in any ways other than scrolling/clicking on buttons to get the audio file playing.
2024-03-20 Workshop framework
2024-04-06 mobile device stylings added and clean-up
2024-05-08 flow chart added
2024-05-08 Cleaned up flowchart
